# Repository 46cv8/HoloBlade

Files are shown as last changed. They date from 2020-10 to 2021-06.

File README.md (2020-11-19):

###################################################################<br/>
HoloBlade: An Open-Hardware Spatial Light Modulator Driver Platform<br/>
###################################################################<br/>

Overview:<br/>
Spatial light modulators (SLMs) are an important tool for applied optics research across a range of diverse fields such as holographic  displays, telecommunications, astronomy, microscopy and optical computing. However, contemporary SLMs are very much a high-end scientific tool and are not very accessible to the wider research community. HoloBlade is an attempt to democratise access to SLMs.<br/>

The primary application for HoloBlade is holographic display applications, but it is also applicable to adjacent research fields utilising SLMs. By providing an open-source SLM driver-stack, it is hoped to makes SLMs lower-cost, more accessbile and to use HoloBlade as a foundation platform to catalyse the development of Holographic Display Systems.

Directory Structure:
- fpga_firmware<br/>
  - verilog:   Main executable code for the FPGA is in here. Several components are generated from myHDL and have to be copied into here.<br/>
  - myHDL:     Most of the individual compoennts are designed, tested and simulated using myHDL and then sythesised to verilog. The myHDL components are in this directory along with scripts for generating them.<br/>
- electronics: Contains the HoloBlade bespoke electronics design files<br/>
- pc_software: Contains the GUI and driver calls to drive the HoloBlade driver-stack. Currently just supports .NET on Windows.<br/>
- mechanical:  STL files for the optomechanical mount for the main electornics board and SLM<br/>
- docs:        Any key supporting documentation (eg: datasheet)<br/>

License:<br/>
HoloBlade is released under the CERN Open Hardware Licence’s permissive variant, CERN-OHL-P v2, see https://cern.ch/cern-ohl.

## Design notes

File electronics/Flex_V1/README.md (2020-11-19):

All PCB files and intermediate files used in ordering the FFC Cable

Ordered from Elecrow.com Premium PCB service: https://www.elecrow.com/premium-pcb-service-p-1061.html

If they haven't changed their procedure, you will need to send the Gerber files (in flex_v1.zip),
PCB requirements (flex_pcb_requirements.xlsx) and the image showing location of stiffeners
(stiffner.png) to service@elecrow.com for a quote.

Leave most of the parameter in the requirements file as is, length, quantity and shipping address should be changed. May be worth testing with 0.5oz
copper as that may be much cheaper but have not tested this.

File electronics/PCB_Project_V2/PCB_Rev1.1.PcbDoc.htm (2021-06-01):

Reporting Options

# File in Previous Format

Date | : | 25/02/2021
Time | : | 10:41:34
Filename | : | D:\Dev\HoloBlade\electronics\PCB_Project_V2\PCB_Rev1.1.PcbDoc

Version | Warning

This file was generated by an earlier version of the software

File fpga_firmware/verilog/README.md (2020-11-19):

Firmware for FPGA to drive the Awesome Board

This firmware can either be run using the Lattice iCEcube2 tools or from the cli by invoking to the toolchain from the cli. A couple of things to note:
  - the iCEcube2 tools are good for configuration, but hard to get any serious amount of work done in (not really an editor/IDE)
  - the above is the main reason why i scripted to call from the cli, I use VSCode and the gitbash/mingw terminal within VSCode to develop the firmware
  - Holoblade_syn.prj and Holoblade_sbt.project will get overwritten by the iCEcube2 tools, so better to modify in there than editing files manually
  - these are the tools to build it, you use a separate tool to program called the Lattice Diamond Programmer
  - when running these tools, need to edit scripts/build.sh to point to root location of this project
  - i also put in the following symbolic link to deal with lattice installation issues: 'ln -s /c/lscc/iCEcube2.2017.08 /c/lscc/iCEcube2.2017.08'

From the CLI, I can compile the entire toolchain with the script with 'source scripts/build.sh'. To do this, need to make sure that the build script knows where the LSE toolchain is installed:
ie, set the following correctly in scripts/build.sh:
# LSE Versions
# Dev PC
# export ICE_ROOT=/d/ProgramFiles/Lattice
# Lab PC
export ICE_ROOT=/c/lscc/iCEcube2.2017.08

Also need to make sure that the programmer is set to the correct binary location and the correct COM port for programming is set. The programmer settings need to be configured in the Diamond Programmer App as a one-off, and then they can be saved and
the programmer can subsequently be run from the scripts here.

The directories are the following:
    - src: verilog code
    - phys: contraints (pin mappings, timing limitations, etc...)
    - scripts: scripts to help call tools from the cli
    - HoloBlade_Implmnt: All of the generated files (there's a lot of them) from the FPGA tools go here. Note that the name of this dir is a limitation of the Lattice tools

Andrew Kadis 6th August 2019

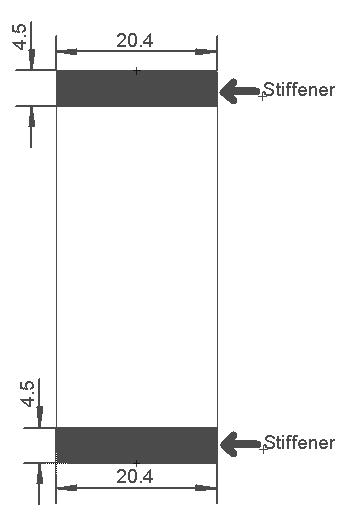
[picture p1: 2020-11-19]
electronics/Flex_V1/stiffener.png

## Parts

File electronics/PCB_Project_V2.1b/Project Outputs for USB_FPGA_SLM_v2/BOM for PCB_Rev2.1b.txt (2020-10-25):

Comment,Description,Designator,Footprint,LibRef,Quantity,Case Code,Mouser No.

"C0603C475K9PAC7411","Multilayer Ceramic Capacitors MLCC - SMD/SMT 6.3V 4.7uF 0603 X5R 10%","C1, C4, C9, C11","Cap_4.7uF","Cap_4.7uF","4","","80-C0603C475K9P7411"
"C1608X5R0J106K080AE","Multilayer Ceramic Capacitors MLCC - SMD/SMT 0603 6.3V 10uF X5R 10% Soft Term","C2, C6, C8, C13","Cap_10uF","Cap_10uF","4","","810-C1608X5R0J106KE"
"AC0603KRX7R9BB104","Multilayer Ceramic Capacitors MLCC - SMD/SMT 0.1uF 10% 50V AEC-Q200","C3, C5, C10, C12, C14, C15, C21, C22, C25, C26, C27, C28, C29, C30, C31, C32, C33, C34, C35, C36, C37, C38, C39, C40, C41, C42, C59, C74","Cap_0.1uF","Cap_0.1uF","28","","603-AC0603KR9BB104"
"C0402S471K3RACAUTO","Multilayer Ceramic Capacitors MLCC - SMD/SMT 25V 470pF X7R 0402 10% AEC-Q200","C7","CAP_470pF","Cap_470pF","1","0603","80-C0402S471K3RAUTO"
"CC0402KPX5R6BB104","Multilayer Ceramic Capacitors MLCC - SMD/SMT 100nF 10V X5R 10%","C16, C19, C23, C24, C44, C45, C46, C48, C49, C50, C51, C52, C53, C54, C55, C56, C62, C63, C64, C65, C66, C67, C68, C70, C72, C75, C76","CAP_0.1UF_0402","CAP_0.1uF_0402","27","0402","603-CC402KPX5R6BB104"
"C1005X5R0J475K050BC","Multilayer Ceramic Capacitors MLCC - SMD/SMT 0402 6.3V 4.7uF X5R 10% T: 0.5mm","C17, C43, C58, C60, C61, C71","CAP_4.7uF_0402","Cap_4.7uF_0402","6","0402","810-C1005X5R0J475K"
"C0603C180K5RACAUTO","Multilayer Ceramic Capacitors MLCC - SMD/SMT 50V 18pF 0603 X7R 10% AEC-Q200","C18, C20","CAP_18pF_0603","Cap_18pF_0603","2","0603","80-C0603C180K5RAUTO"
"C0402C682K5RECAUTO","Multilayer Ceramic Capacitors MLCC - SMD/SMT 50V 6800pF X7R 0402 10% AEC-Q200","C47, C57, C69","CAP_6700pF_0402","Cap_6800pF_0402","3","0402","80-C0402C682K5RECAUT"
"PGB1010402KR","ESD Suppressors / TVS Diodes PULSEGUARD 0402 ESD SUPPRESSOR","D1, D2","ESD_Suppressor","ESD_Suppresor","2","0402","576-PGB1010402KR"
"CDBU0520","Schottky Diodes & Rectifiers VR=20V, IO=500mA","D3","SchottkyDiode_CDBU0520","SDiode_CDBU0520","1","0603","750-CDBU0520"
"Header 3","Header, 3-Pin","DB7, DB8, GP0, GP1, RST, SIWU, WR","HDR1X3","Header 3","7","",""
"629105136821","Micro USB 2.0 Type B Receptacle WR-COM, Horizontal, SMT, with Pads and Pegs","J1","629105136821","629105136821","1","",""
"692622030100","Micro USB 3.0 Type B Receptacle WR-COM, Horizontal, SMT, with Pads","J2","692622030100","692622030100","1","",""
"FH39A-67S-0.3SHW(10)","FFC & FPC Connectors FPC ZIF CONN 67 POS SMT HORZ MNT","J3","Hirose_connector","FH39A-67S-0.3SHW(10)","1","","798-FH39A-67S-0.3SHW(10)"
"742863160","Ferrite Bead, 0603 [1608 Metric], 600 ohm, 500 mA, WE-CBF HF Series, 0.35 ohm, ± 25%","L1, L2","FerriteBeads","Ferrite Bead","2","0603","710-742863160"
"BLM18PG300SZ1D","Ferrite Beads 0603 30ohms 1000mA Auto Infotainment","L3","FerriteBeads","FerriteBeadForFT601","1","0603","81-BLM18PG300SZ1D"
"TLMS1000-GS08","Standard LEDs - SMD RED","LED1, LED2, LED3, LED4, LED5, LED6, LED7","LED_RED","LED_RED","7","0603","78-TLMS1000"
"Header 2","Header, 2-Pin","P1, P3, P5","HDR1X2","Header 2","3","",""
"Header 4","Header, 4-Pin","P2, P7","HDR2X2","Header 4","2","",""
"Header 3X2","Header, 3-Pin, Dual row","P6-GND","HDR2X3","Header 3X2","1","",""
"RT0603FRE13680RL","Thin Film Resistors - SMD 680 ohm 1% 50 ppm Thin Film","R1, R3, R21, R22, R23, R26, R36, R48","RES_680","Res_680","8","0603","603-RT0603FRE13680RL"
"CRCW06032K20JNEAC","Thick Film Resistors - SMD 1/10Watt 2.2Kohms 5% Commercial Use","R2, R6, R11","RES_2.2K","Res_2.2K","3","0603","71-CRCW06032K20JNEAC"
"ERJ2RKD33R0X","Thick Film Resistors - SMD 0402 Resistor 0.5% 100ppm 33Ohm","R4","Res_33_0402","Res_33_0402","1","0402","667-ERJ-2RKD33R0X"
"RT0603WRE0710KL","Thin Film Resistors - SMD 10K ohm 0.05% 50 ppm High-Precision","R5, R7, R8, R9, R14, R15, R17, R18, R25, R27, R39","RES_10K","Res_10K","11","0603","603-RT0603WRE0710KL"
"ERJ-3RBD1601V","Thick Film Resistors - SMD 0603 Resistor 0.5% 50ppm 1.6KOhm","R10","RES_1.6K","Res_1.6K","1","0603","667-ERJ-3RBD1601V"
"AC0603FR-1012KL","Thick Film Resistors - SMD 12K ohm 1% 1/10W AEC-Q200","R12","RES_12K","Res_12K","1","0603","603-AC0603FR-1012KL"
"CRCW06030000Z0EAC","Thick Film Resistors - SMD 1/10Watt 0ohms Commercial Use","R13, R16, R24, R30, R31, R32, R33, R34, R35, R37, R38, R40, R41, R42, R43, R44, R45, R46, R47","RES_0","Res_0","19","0603","71-CRCW06030000Z0EAC"
"AC0603JR-134K7L","Thick Film Resistors - SMD 4.7K ohm 5% 1/10W AEC-Q200","R19","RES_4.7K","Res_4.7K","1","0603","603-AC0603JR-134K7L"
"SR0603KR-07100KL","Thick Film Resistors - SMD 100K ohm 10% 75V AEC-Q200","R20","RES_100K","Res_100K","1","0603","603-SR0603KR-07100KL"
"SR0603KR-07100KL","Thick Film Resistors - SMD 100K ohm 10% 75V AEC-Q200","R49, R52","RESC1607X60N","Res_100K","2","0603","603-SR0603KR-07100KL"
"EXB-2HVR000V","Resistor Networks & Arrays 0402 Zero ohm Jumper Convex Term AEC-Q200","RN1, RN2","RESARRAY_0","ResArray_0","2","0402","667-EXB-2HVR000V"
"EXB-2HV330JV","Resistor Networks & Arrays 33 OHM 5%","RN3, RN4, RN5, RN6, RN7, RN8, RN9, RN10, RN11","RESARRAY_0","ResArray","9","","667-EXB-2HV330JV"
"SKU : COM-00097SMT- SWCH-08247","","S1","TACTILE-PTH","TAC_SWITCHPTH","1","",""
"testpoint","Testpoint for testing voltage","TP1, TP2, TP3, TP4, TP5, TP6, TP8, TP9","testpoint","Testpoint","8","",""
"MCP1700T-1202E/TT","LDO Voltage Regulators 250mA Adj LDO 2%","U1","MIC_LDO_1V2","MIC_LDO_1V2","1","","579-MCP1700T1202E/TT"
"MIC5205YM5-TR","LDO Voltage Regulators 150mA 1% Low Noise LDO","U2","MIC5205YM5","MIC5205YM5","1","","998-MIC5205YM5TR"
"MCP1700T-3302E/TT","3.3v LDO Voltage Regulators 250mA Adj LDO 2%","U3","MIC_LDO_3V3","MIC_LDO_3V3","1","","579-MCP1700T3302E/TT"
"LM1117MP-2.5/NOPB","LDO Voltage Regulators 800mA LDO Linear Reg","U4","LM1117MP-2.5/NOPB","LDO_2V5","1","","926-LM1117MP-2.5/NOPB"
"ICE40HX4K-TQ144","iCE40 HX4K Series FPGA Family, 3520 Logic Cells, 1.2 V Core, 80 K Embedded RAM Bits, 144-pin TQFP, Pb-Free, Tray","U5","LATC-TQFP-144_L","ICE40HX4K-TQ144","1","",""
"FT2232HL-Reel","Dual High Speed USB To Multipurpose UART/FIFO IC, 64-pin LQFP, Tape and Reel","U6","LQFP-64_N","FT2232HL-Reel","1","",""
"93LC56BT-E/MS","EEPROM 128x16 for FT2232","U7","EEPROM","EEPROM","1","","579-93LC56BT-E/MS"
"FT601Q-B-T","USB Interface IC USB 3.0 Super-Speed 32Bits Sync FIFO","U8","FT601_NoGND_Pad","FT601Q-B-T","1","",""
"MT25QL128ABA1ESE-0SIT TR","NOR Flash SPI FLASH NOR SLC 32MX4 SOIC","U9","Flash","Flash","1","","340-224871-REEL"
"TXS0108EPWR","Integrated Circuit","U10","SOP65P640X120-20N","Level_Shfter_8bits","1","",""
"DSC6101JI2A-024.0000","Standard Clock Oscillators MEMS Oscillator, Ultra Low Power, LVCMOS, -40C-85C, 25ppm, 2.5x2.0mm","X1","24MHzOscillator","24MHzOscillator","1","","579-C6101JI2A0240000"
"ABM8G-30.000MHZ-18-D2Y-T","Crystals 30.000MHz 18pF 30ppm -40C +85C","X2","30MHzOscillatorV2","30MHzOscillator","1","",""
"ECS-3225S33-120-FN-TR","Standard Clock Oscillators 12MHz 3.3V 10ppm -40C +85C","X3","12MHzOscillator","12MHzOscillator","1","","520-3225S33-120-FNT"

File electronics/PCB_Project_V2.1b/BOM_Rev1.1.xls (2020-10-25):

Item | Comment | Description | Designator | Footprint | LibRef | Package | Quantity | Unit Price | Price for each component | NOTE
1 | C0603C475K9PAC7411 | Multilayer Ceramic Capacitors MLCC - SMD/SMT 6.3V 4.7uF 0603 X5R 10% | C1, C4, C9, C11 | Cap_4.7uF | Cap_4.7uF | 0603 | 4 |  | US$0.0000
2 | C1608X5R0J106K080AE | Multilayer Ceramic Capacitors MLCC - SMD/SMT 0603 6.3V 10uF X5R 10% Soft Term | C2, C6, C8, C13 | Cap_10uF | Cap_10uF | 0603 | 4 |  | US$0.0000 | 5-7work days
3 | AC0603KRX7R9BB104 | Multilayer Ceramic Capacitors MLCC - SMD/SMT 0.1uF 10% 50V AEC-Q200 | C3, C5, C10, C12, C14, C15, C21, C22, C25, C26, C27, C28, C29, C30, C31, C32, C33, C34, C35, C36, C37, C38, C39, C40, C41, C42, C59, C74 | Cap_0.1uF | Cap_0.1uF | 0603 | 28 |  | US$0.0000
4 | C0402S471K3RACAUTO | Multilayer Ceramic Capacitors MLCC - SMD/SMT 25V 470pF X7R 0402 10% AEC-Q200 | C7 | CAP_470pF | Cap_470pF | 0402 | 1 |  | US$0.0000 | 5-7work days
5 | CC0402KPX5R6BB104 | Multilayer Ceramic Capacitors MLCC - SMD/SMT 100nF 10V X5R 10% | C16, C19, C23, C24, C44, C45, C46, C48, C49, C50, C51, C52, C53, C54, C55, C56, C62, C63, C64, C65, C66, C67, C68, C70, C72, C75, C76 | CAP_0.1UF_0402 | CAP_0.1uF_0402 | 0402 | 27 |  | US$0.0000
6 | C1005X5R0J475K050BC | Multilayer Ceramic Capacitors MLCC - SMD/SMT 0402 6.3V 4.7uF X5R 10% T: 0.5mm | C17, C43, C58, C60, C61, C71 | CAP_4.7uF_0402 | Cap_4.7uF_0402 | 0402 | 6 |  | US$0.0000 | 5-7work days
7 | C0603C180K5RACAUTO | Multilayer Ceramic Capacitors MLCC - SMD/SMT 50V 18pF 0603 X7R 10% AEC-Q200 | C18, C20 | CAP_18pF_0603 | Cap_18pF_0603 | 0603 | 2 |  | US$0.0000
8 | C0402C682K5RECAUTO | Multilayer Ceramic Capacitors MLCC - SMD/SMT 50V 6800pF X7R 0402 10% AEC-Q200 | C47, C57, C69 | CAP_6700pF_0402 | Cap_6800pF_0402 | 0402 | 3 |  | US$0.0000 | 5-7work days
9 | PGB1010402KR | ESD Suppressors / TVS Diodes PULSEGUARD 0402 ESD SUPPRESSOR | D1, D2 | ESD_Suppressor | ESD_Suppresor | 0402 | 2 |  | US$0.0000
10 | CDBU0520 | Schottky Diodes & Rectifiers VR=20V, IO=500mA | D3 | SchottkyDiode_CDBU0520 | SDiode_CDBU0520 | 0603 | 1 |  | US$0.0000 | 5-7work days
11 | 629105136821 | Micro USB 2.0 Type B Receptacle WR-COM, Horizontal, SMT, with Pads and Pegs | J1 | 629105136821 | 629105136821 | USB3 | 1 |  | US$0.0000 | 5-7work days
12 | 692622030100 | Micro USB 3.0 Type B Receptacle WR-COM, Horizontal, SMT, with Pads | J2 | 692622030100 | 692622030100 | USB2 | 1 |  | US$0.0000 | 5-7work days
13 | FH39A-67S-0.3SHW(10) | FFC & FPC Connectors FPC ZIF CONN 67 POS SMT HORZ MNT | J3 | Hirose_connector | FH39A-67S-0.3SHW(10) |  | 1 |  | US$0.0000 | 5-7work days
14 | 742863160 | Ferrite Bead, 0603 [1608 Metric], 600 ohm, 500 mA, WE-CBF HF Series, 0.35 ohm, ± 25% | L1, L2 | FerriteBeads | Ferrite Bead | 0603 | 2 |  | US$0.0000 | 5-7work days
15 | BLM18PG300SZ1D | Ferrite Beads 0603 30ohms 1000mA Auto Infotainment | L3 | FerriteBeads | FerriteBeadForFT601 | 0603 | 1 |  | US$0.0000 | 5-7work days
16 | TLMS1000-GS08 | Standard LEDs - SMD RED | LED1, LED2, LED3, LED4, LED5, LED6, LED7 | LED_RED | LED_RED | 0603 | 7 |  | US$0.0000
17 | RT0603FRE13680RL | Thin Film Resistors - SMD 680 ohm 1% 50 ppm Thin Film | R1, R3, R21, R22, R23, R26, R36, R48 | RES_680 | Res_680 | 0603 | 8 |  | US$0.0000
18 | CRCW06032K20JNEAC | Thick Film Resistors - SMD 1/10Watt 2.2Kohms 5% Commercial Use | R2, R6, R11 | RES_2.2K | Res_2.2K | 0603 | 3 |  | US$0.0000
19 | ERJ2RKD33R0X | Thick Film Resistors - SMD 0402 Resistor 0.5% 100ppm 33Ohm | R4, R28, R29 | Res_33_0402 | Res_33_0402 | 0402 | 3 |  | US$0.0000 | 5-7work days
20 | RT0603WRE0710KL | Thin Film Resistors - SMD 10K ohm 0.05% 50 ppm High-Precision | R5, R7, R8, R9, R14, R15, R17, R18, R25, R27, R39 | RES_10K | Res_10K | 0603 | 11 |  | US$0.0000 | 5-7work days
21 | ERJ-3RBD1601V | Thick Film Resistors - SMD 0603 Resistor 0.5% 50ppm 1.6KOhm | R10 | RES_1.6K | Res_1.6K | 0603 | 1 |  | US$0.0000 | 5-7work days
22 | AC0603FR-1012KL | Thick Film Resistors - SMD 12K ohm 1% 1/10W AEC-Q200 | R12 | RES_12K | Res_12K | 0603 | 1 |  | US$0.0000
23 | CRCW06030000Z0EAC | Thick Film Resistors - SMD 1/10Watt 0ohms Commercial Use | R13, R16, R24, R30, R31, R32, R33, R34, R35, R37, R38, R40, R41, R42, R43, R44, R45, R46, R47 | RES_0 | Res_0 | 0603 | 19 |  | US$0.0000
24 | AC0603JR-134K7L | Thick Film Resistors - SMD 4.7K ohm 5% 1/10W AEC-Q200 | R19 | RES_4.7K | Res_4.7K | 0603 | 1 |  | US$0.0000
25 | SR0603KR-07100KL | Thick Film Resistors - SMD 100K ohm 10% 75V AEC-Q200 | R20 | RES_100K | Res_100K | 0603 | 1 |  | US$0.0000
26 | EXB-2HVR000V | Resistor Networks & Arrays 0402 Zero ohm Jumper Convex Term AEC-Q200 | RN1, RN2 | RESARRAY_0 | ResArray_0 | 0402 Array | 2 |  | US$0.0000 | 5-7work days
27 | EXB-2HV330JV | Resistor Networks & Arrays 33 OHM 5% | RN3, RN4, RN5, RN7, RN8, RN6, RN9, RN10, RN11 | RESARRAY_0 | ResArray | 0402 Array | 9 |  | US$0.0000 | 5-7work days
28 | MCP1700T-1202E/TT | LDO Voltage Regulators 250mA Adj LDO 2% | U1 | MIC_LDO_1V2 | MIC_LDO_1V2 | SOT-23-3 | 1 |  | US$0.0000
29 | MIC5205YM5-TR | LDO Voltage Regulators 150mA 1% Low Noise LDO | U2 | MIC5205YM5 | MIC5205YM5 | SOT-23-5 | 1 |  | US$0.0000
30 | MCP1700T-3302E/TT | 3.3v LDO Voltage Regulators 250mA Adj LDO 2% | U3 | MIC_LDO_3V3 | MIC_LDO_3V3 | SOT-23-3 | 1 |  | US$0.0000
31 | LM1117MP-2.5/NOPB | LDO Voltage Regulators 800mA LDO Linear Reg | U4 | LM1117MP-2.5/NOPB | LDO_2V5 | SOT-223-4 | 1 |  | US$0.0000
32 | ICE40HX4K-TQ144 | iCE40 HX4K Series FPGA Family, 3520 Logic Cells, 1.2 V Core, 80 K Embedded RAM Bits, 144-pin TQFP, Pb-Free, Tray | U5 | LATC-TQFP-144_L | ICE40HX4K-TQ144 | TQFP-144 | 1 |  | US$0.0000 | 5-7work days
33 | FT2232HL-Reel | Dual High Speed USB To Multipurpose UART/FIFO IC, 64-pin LQFP, Tape and Reel | U6 | LQFP-64_N | FT2232HL-Reel | LQFP-64 | 1 |  | US$0.0000
34 | 93LC56BT-E/MS | EEPROM 128x16 for FT2232 | U7 | EEPROM | EEPROM | MSOP-8 | 1 |  | US$0.0000 | 5-7work days
35 | FT601Q-B-T | USB Interface IC USB 3.0 Super-Speed 32Bits Sync FIFO | U8 | FT601_NoGND_Pad | FT601Q-B-T | 76-QFN | 1 |  | US$0.0000 | 5-7work days
36 | MT25QL128ABA1ESE-0SIT TR | NOR Flash SPI FLASH NOR SLC 32MX4 SOIC | U9 | Flash | Flash | SOP2-8 | 1 |  | US$0.0000
37 | TXS0108EPWR | Integrated Circuit | U10 | SOP65P640X120-20N | Level_Shfter_8bits | TSSOP-20 | 1 |  | US$0.0000
38 | DSC6101JI2A-024.0000 | Standard Clock Oscillators MEMS Oscillator, Ultra Low Power, LVCMOS, -40C-85C, 25ppm, 2.5x2.0mm | X1 | 24MHzOscillator | 24MHzOscillator | VLGA-4 | 1 |  | US$0.0000 | 5-7work days
39 | ABM8G-30.000MHZ-18-D2Y-T | Crystals 30.000MHz 18pF 30ppm -40C +85C | X2 | 30MHzOscillatorV2 | 30MHzOscillator | SMD/SMT | 1 |  | US$0.0000 | 5-7work days
40 | ECS-3225S33-120-FN-TR | Standard Clock Oscillators 12MHz 3.3V 10ppm -40C +85C | X3 | 12MHzOscillator | 12MHzOscillator | 6-SMD, No Lead | 1 |  | US$0.0000 | 5-7work days
 |  |  |  |  |  | Total | 163 |  | $0.000
 |  |  |  |  |  |  |  | Total amount for 5sets | US$0
 |  |  |  |  |  |  |  | Total weight
 |  |  |  |  |  |  |  | Quote based on Comment

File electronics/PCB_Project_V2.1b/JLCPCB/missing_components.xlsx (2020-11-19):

Designator | Comment | Footprint | Quantity
L3 | BLM18PG300SZ1D | FERRITEBEADS | 1
J3 | FH39A-67S-0.3SHW(10) | HIROSE_CONNECTOR | 1
D3 | CDBU0520 | SCHOTTKYDIODE_CDBU0520 | 1
L1,L2 | 742863160 | FERRITEBEADS | 2
C7 | C0402S471K3RACAUTO | CAP_470PF | 1
U3 | MCP1700T-3302E/TT | MIC_LDO_3V3 | 1
C2,C6,C8,C13 | C1608X5R0J106K080AE | CAP_10UF | 4
C1,C4,C9,C11 | C0603C475K9PAC7411 | CAP_4.7UF | 4
D1,D2 | PGB1010402KR | ESD_SUPPRESSOR | 2
U1 | MCP1700T-1202E/TT | MIC_LDO_1V2 | 1
U2 | MIC5205YM5-TR | MIC5205YM5 | 1
U6 | FT2232HL-REEL | LQFP-64_N | 1
U10 | TXS0108EPWR | SOP65P640X120-20N | 1
R4 | ERJ2RKD33R0X | RES_33_0402 | 1
LED1,LED2,LED3,LED4,LED5,LED6,LED7 | TLMS1000-GS08 | LED_RED | 7
R13,R16,R24,R30,R31,R32,R33,R34,R35,R37,R38,R40,R41,R42,R43,R44,R45,R46,R47 | CRCW06030000Z0EAC | RES_0 | 19
R19 | AC0603JR-134K7L | RES_4.7K | 1
R2,R6,R11 | CRCW06032K20JNEAC | RES_2.2K | 3
J2 | 692622030100 | 692622030100 | 1
R10 | ERJ-3RBD1601V | RES_1.6K | 1
X1 | DSC6101JI2A-024.0000 | 24MHZOSCILLATOR | 1
P6-GND | HEADER 3X2 | HDR2X3 | 1
X2 | ABM8G-30.000MHZ-18-D2Y-T | 30MHZOSCILLATORV2 | 1
P1,P3,P5 | HEADER 2 | HDR1X2 | 3
RN3,RN4,RN5,RN6,RN7,RN8,RN9,RN10,RN11 | EXB-2HV330JV | RESARRAY_0 | 9
U8 | FT601Q-B-T | FT601_NOGND_PAD | 1
U7 | 93LC56BT-E/MS | EEPROM | 1
R20 | SR0603KR-07100KL | RES_100K | 1
U4 | LM1117MP-2.5/NOPB | LM1117MP-2.5/NOPB | 1
U9 | MT25QL128ABA1ESE-0SIT TR | FLASH | 1
TP1,TP2,TP3,TP4,TP5,TP6,TP8,TP9 | TESTPOINT | TESTPOINT | 8
U5 | ICE40HX4K-TQ144 | LATC-TQFP-144_L | 1
R12 | AC0603FR-1012KL | RES_12K | 1
DB7,DB8,GP0,GP1,RST,SIWU,WR | HEADER 3 | HDR1X3 | 7
C18,C20 | C0603C180K5RACAUTO | CAP_18PF_0603 | 2
RN1,RN2 | EXB-2HVR000V | RESARRAY_0 | 2
J1 | 629105136821 | 629105136821 | 1
P2,P7 | HEADER 4 | HDR2X2 | 2
S1 | SKU : COM-00097SMT- SWCH-08247 | TACTILE-PTH | 1
X3 | ECS-3225S33-120-FN-TR | 12MHZOSCILLATOR | 1

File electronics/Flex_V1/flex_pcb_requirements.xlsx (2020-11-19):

Premium PCB Service Technology Requirement
PCB Name & Version | flex v0.1
PCB Material PCB板材： | (Rigid)FR－4 Flex | PCB Qty PCB 数量 | （ 30 ）
PCB Size PCB大小： | cm mm inch | ( 20.4 ) × ( 50 )
PCB Layer PCB层数： | 2 | 4 | other:( 1 )
Thickness PCB厚度： | 0.8mm | 1.2mm | other:( 0.2mm )
 | 1mm | 1.6mm
Copper Weight 铜厚： | 1oz | 2oz | other:( )
PCB Colour 阻焊颜色： | Green 绿色 | White 白色 | Black 黑色
 | Red 红色 | Blue 蓝色 | other:( )
Silkscreen 字符颜色： | White 白色 | Black 黑色 | other:( None )
Pads Finished 焊盘喷镀： | (Hasl-lead free) 无铅喷锡 | (Hasl) 含铅喷锡 | (ENIG) 沉镍金
Via solder mask 阻焊覆盖： | solder mask cover 过孔盖油 | solder mask opening 过孔开窗 | No vias
Minimum trace/space (mm) 最小线宽 | 0.1mm | Minimum hole size (mm) 最小孔径 | No holes
Special requirements 特殊工艺： | Yes | (Put requirements here)
价格/Price | Premium PCB service | PCB with normal price | The PCB with normal price is listed online, If there isn't a choice meets your requirement, get quotation off-line.
Comment: | Stiffner specified in attached image
Shipping Address | 43 Princess Court Cambridge - CB2 1JJ - UK

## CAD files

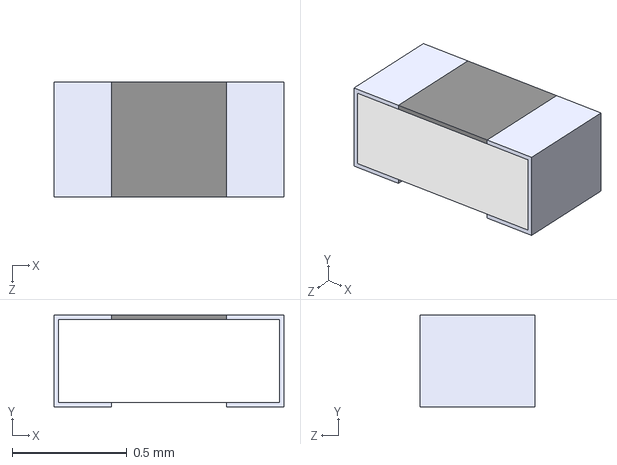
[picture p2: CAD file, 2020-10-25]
electronics/PCB_Project_V2.1b/ERJ2RKD33R0X.STEP
1 x 0.4 x 0.5 mm

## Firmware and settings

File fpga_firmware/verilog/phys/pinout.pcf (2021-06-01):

# ##############################################################################

# iCEcube PCF

# Version:            2017.08.27940

# Family & Device:    iCE40HX4K

# Package:            TQ144

# ##############################################################################

###IOSet List 4

# FPGA
set_io ICE_SYSCLK 93

# Debug
set_io DEBUG_5 81
set_io DEBUG_6 82
set_io DEBUG_0 83
set_io DEBUG_1 84
set_io DEBUG_2 85
set_io DEBUG_3 87
# NetTP8
set_io DEBUG_8 63
# NetTP9
set_io DEBUG_9 64

# FT2232H UART
set_io DCD 73
set_io DSR 74
set_io DTR 75
set_io CTS 76
set_io RST 78
set_io UART_TX 79
set_io UART_RX 80

# SPI
set_io SEN 141
set_io SCK 144
set_io SOUT 139
set_io SDAT 143

# Bluejay Control
# Control Signals
set_io UPDATE 88
set_io RESET 142
set_io SLM_CLK 95
set_io INVERT 91
set_io SYNC 90
set_io VALID 94

# Data
set_io DATA31 137 
set_io DATA0  138 
set_io DATA30 136 
set_io DATA29 135
set_io DATA1  134
set_io DATA28 130
set_io DATA27 129
set_io DATA2  128
set_io DATA26 125
set_io DATA25 124
set_io DATA3  122
set_io DATA24 121
set_io DATA23 120
set_io DATA4  119
set_io DATA22 118
set_io DATA21 117
set_io DATA5  116
set_io DATA20 115
set_io DATA19 114
set_io DATA6  113
set_io DATA18 112
set_io DATA17 110
set_io DATA7  107
set_io DATA16 106
set_io DATA15 105
set_io DATA8  104
set_io DATA14 102
set_io DATA13 101
set_io DATA9  99
set_io DATA12 98
set_io DATA11 97
set_io DATA10 96

# FT601
# Bank 3 Pins
set_io DEBUG_N_8 1 # Created as DEBUG_N_8 was not defined prior but used to map to TP7 on board
set_io FT_OE 2
set_io FT_RD 3
set_io FT_WR 4 # Can be used as debug point when configured with jumper
set_io FT_SIWU 7 # Can be used as debug point when configured with jumper
set_io FR_RXF 8
set_io FT_TXE 9
# set_io FIFO_BE3 10 # Changing to FT_RESET was FIFO_BE3 AND can be used as debug point when configured with jumper
set_io FT_RESET 10 # Changing to FT_RESET was FIFO_BE3 AND can be used as debug point when configured with jumper
# set_io FIFO_BE2 11 # Changing to FT_GPIO0 was FIFO_BE2 AND can be used as debug point when configured with jumper
set_io FT_GPIO0 11 # Changing to FT_GPIO0 was FIFO_BE2 AND can be used as debug point when configured with jumper
#  set_io FIFO_BE1 12 # Changing to FT_GPIO1 was FIFO_BE1 AND can be used as debug point when configured with jumper
set_io FT_GPIO1 12 # Changing to FT_GPIO1 was FIFO_BE1 AND can be used as debug point when configured with jumper
# set_io FIFO_BE0 15 # Changed to DEBUG_N_7 was FIFO_BE0 AND can be used as debug point when configured with jumper
set_io DEBUG_N_7 15 # Changed to DEBUG_N_7 was FIFO_BE0 AND can be used as debug point when configured with jumper
set_io FIFO_D31 16
set_io FIFO_D30 17
set_io FIFO_D29 18
set_io FIFO_D28 19
set_io FIFO_D27 20
set_io FIFO_CLK 21
set_io FIFO_D26 22
set_io FIFO_D25 23
set_io FIFO_D24 24
set_io FIFO_D23 25
set_io FIFO_D22 26
set_io FIFO_D21 28
set_io FIFO_D20 29
set_io FIFO_D19 31
set_io FIFO_D18 32
set_io FIFO_D17 33
set_io FIFO_D16 34
# Bank 2 Pins
set_io FIFO_D15 37
set_io FIFO_D14 38
set_io FIFO_D13 39
set_io FIFO_D12 41
set_io FIFO_D11 42
set_io FIFO_D10 43
set_io FIFO_D9  44
set_io FIFO_D8  45
set_io FIFO_D7  47
set_io FIFO_D6  48
set_io FIFO_D5  49
set_io FIFO_D4  55
set_io FIFO_D3  56
set_io FIFO_D2  60
set_io FIFO_D1  61
set_io FIFO_D0  62

# Programming
#set_io ICE_CLK 52 # for linux build it doesn't seem to properly assign tri-state so we need to manually create another net so we can use the SB_IO or SB_GB_IO primitives commented out for now as its unused
#set_io ICE_CDONE 65 # for linux build can't bind to pin 65 removing https://github.com/YosysHQ/icestorm/issues/269
#set_io ICE_CREST 66 # for linux build can't bind to pin 66 removing https://github.com/YosysHQ/icestorm/issues/269
#set_io ICE_MISO 67
#set_io ICE_MOSI 68
#set_io ICE_SCK  70
#set_io ICE_SS_B 71

# Unused

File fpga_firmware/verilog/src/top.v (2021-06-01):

/* 
* Top module for HoloBlade Board
*/

module top(

    // FPGA
    input ICE_SYSCLK, 

    // FT2232H UART
    output DCD,
    output DSR,
    output DTR,
    output CTS,
    output RST,
    input  UART_RX,
    output UART_TX,

    // Bluejay SPI
    output SEN,
    output SCK,
    input  SOUT, // ie: MISO
    output SDAT, // ie: MOSI

    // Bluejay Control
    // Control Signals
    output UPDATE,
    output RESET,
    output SLM_CLK,
    output INVERT,
    output SYNC,
    output VALID,
    // Data
    output DATA31,
    output DATA0,
    output DATA30,
    output DATA29,
    output DATA1,
    output DATA28,
    output DATA27,
    output DATA2,
    output DATA26,
    output DATA25,
    output DATA3,
    output DATA24,
    output DATA23,
    output DATA4,
    output DATA22,
    output DATA21,
    output DATA5,
    output DATA20,
    output DATA19,
    output DATA6,
    output DATA18,
    output DATA17,
    output DATA7,
    output DATA16,
    output DATA15,
    output DATA8 ,
    output DATA14,
    output DATA13,
    output DATA12,
    output DATA11,
    output DATA9,
    output DATA10,

    // FT601
    // Bank 1 Pins
    output DEBUG_N_8, // was not defined before but corresponded to TP7 on new header on V2.1b board (now debug output)
    output FT_OE,
    output FT_RD,
    output FT_WR, // (can be used as a debug output when jumper is set on V2.1b board)
    output FT_SIWU, // (can be used as a debug output when jumper is set on V2.1b board)
    input  FR_RXF,
    input  FT_TXE,
    // input  FIFO_BE3, // same pin as output FT_RESET on V2.1b board
    output FT_RESET, // same as input FIFO_BE3 on V1.1 board (can be used as a debug output when jumper is set on V2.1b board)
    // input  FIFO_BE2, // same pin as output FT_GPIO0 on V2.1b board
    // input FT_GPIO0, // same as input FIFO_BE2 on V1.1 board
    output FT_GPIO0, // same as input FIFO_BE2 on V1.1 board (can be used as a debug output when jumper is set on V2.1b board)
    // input  FIFO_BE1, // same pin as output FT_GPIO1 on V2.1b board
    // input FT_GPIO1, // same as input FIFO_BE1 on V1.1 board
    output FT_GPIO1, // same as input FIFO_BE1 on V1.1 board (can be used as a debug output when jumper is set on V2.1b board)
    // input  FIFO_BE0, // same pin as output DEBUG_N_7 on V2.1b board
    output DEBUG_N_7, // same as input FIFO_BE0 on V1.1 board (now debug output)
    input  FIFO_D31,
    input  FIFO_D30,
    input  FIFO_D29,
    input  FIFO_D28,
    input  FIFO_D27,
    input  FIFO_CLK,
    input  FIFO_D26,
    input  FIFO_D25,
    input  FIFO_D24,
    input  FIFO_D23,
    input  FIFO_D22,
    input  FIFO_D21,
    input  FIFO_D20,
    input  FIFO_D19,
    input  FIFO_D18,
    input  FIFO_D17,
    input  FIFO_D16,
    // Bank 2 Pins
    input FIFO_D15,
    input FIFO_D14,
    input FIFO_D13,
    input FIFO_D12,
    input FIFO_D11,
    input FIFO_D10,
    input FIFO_D9,
    input FIFO_D8,
    input FIFO_D7,
    input FIFO_D6,
    input FIFO_D5,
    input FIFO_D4,
    input FIFO_D3,
    input FIFO_D2,
    input FIFO_D1,
    input FIFO_D0,

    // Debug
    output DEBUG_0,
    output DEBUG_1,
    output DEBUG_2,
    output DEBUG_3,
    output DEBUG_5,
    output DEBUG_6,
    output DEBUG_8,
    output DEBUG_9
    //

    // Programming Pins
    //output ICE_CLK, // for linux build it doesn't seem to properly assign tri-state to this output resulting in a pulldown of the usb clock so I've just disabled it for now
    //output ICE_CDONE, // for linux build can't bind to pin 65 removing https://github.com/YosysHQ/icestorm/issues/269
    //output ICE_CREST, // for linux build can't bind to pin 66 removing https://github.com/YosysHQ/icestorm/issues/269
    //output ICE_MISO,
    //output ICE_MOSI,
    //output ICE_SCK ,
    //output ICE_SS_B,

    // Unused Pins
    // output UNUSED_63,
    // output UNUSED_64

);




// assign DEBUG_0 = 1;
// assign DEBUG_1 = 0;//CLK;
// assign DEBUG_2 = 1;
// assign DEBUG_3 = sysclk_unbuf;





// Route the Uart Rx out of the chip
// assign DEBUG_3 = UART_RX;













////////////////////////
/////// Debug //////////
////////////////////////
// GPIOs for Debug
wire debug_ch1;
wire debug_ch2;
wire debug_ch3;
wire debug_ch4;
// Map to scope probes
// assign DEBUG_9 = debug_ch1; // Goes to TP9
// assign DEBUG_8 = debug_ch2; // Goes to TP8
// assign DEBUG_5 = debug_ch3; // Goes to p5
// assign DEBUG_6 = debug_ch4; // Goes to p6
// GPIOs attached to LEDs
wire debug_led2;
wire debug_led3;
wire debug_led4;
assign DEBUG_0 = debug_led4;


// Temp for LA
wire DEBUG_4;
wire DEBUG_7;
assign DEBUG_4 = DEBUG_9;
assign DEBUG_7 = DEBUG_8;

// assign DEBUG_1 = debug_led3;
// assign DEBUG_2 = debug_led2;
// Drive unused pins to High-Impedance Output
// assign DEBUG_5 = 1'bz;
// assign DEBUG_6 = 1'bz;

// Route out clock
// assign debug_ch1 = fpga_clk;

// LEDs - drive them with a counter
// Counter 
reg [31:0] led_counter = 32'b0;
always @ (posedge fpga_clk) begin
    led_counter <= led_counter + 1;
end
assign debug_led4 = led_counter[24];










////////////////////////
//////// FPGA //////////
////////////////////////

// Clock
wire fpga_clk;
clock clock_inst(

  // Main Clock
  .i_xtal(ICE_SYSCLK),
  .o_sys_clk(fpga_clk)
	
 );

// Reset lines - all driven off a single signal
wire reset_all_cmd_w;
reg reset_all_cmd_r = 1;                     // Start with High on as we want to reset at startup
assign reset_all_cmd_w = reset_all_cmd_r;
// TODO: Reset pulses low for 100ms
/*******************************************************************
************* Clock Divider from 50MHz to 1MHz *********************
*******************************************************************/
// Module to step 50MHz System Clock down to 1Hz Clock for SPI
// reg spi_clk;
wire reset_all_w;
reg reset_all_r = 0;
reg[3:0] reset_clk_counter = reset_countdown; // Start at reset_countdown as we want to reset at startup
// We need to hold reset dow for at least tReset (100ns)
// Hence if we pulse for 10 cycles at 50MHz, this is 200ns, plenty of headroom
parameter reset_countdown = 4'd10;
always @ (posedge fpga_clk) begin
  
  // Default state is no reset
  reset_all_r <= 0;

	if(reset_all_cmd_w==1) begin
		// Start reset countdown if command has been given
		reset_clk_counter <= reset_countdown;
    reset_all_r <= 1;
	end else begin
    // Counting down, pull reset high and decrement
    if(reset_clk_counter>0) begin
      // Decrement and hold reset high
  	  reset_clk_counter <= reset_clk_counter - 1'b1;
      reset_all_r <= 1;
    end
  end

end
// Route out the register pulse value from above to the reset wire
assign reset_all_w = reset_all_r;

// Debug
// assign debug_ch4 = debug_check;
// assign debug_ch4 = reset_all_w;

// Debug
// assign debug_ch1 = UART_RX;
// assign debug_ch2 = UART_TX;
// assign debug_ch4 = start_tx;
// assign debug_ch2 = spi_busy_falling_edge;
// assign debug_ch4 = spi_busy;
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

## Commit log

2020-10-25 version 2.1b pcb
    [BOM for PCB_Rev2.1b.csv, BOM for PCB_Rev2.1b.xls, BOM_Rev1.1.xls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]
2020-10-25 added notes for v2.1b pcb design optional debug outputs and removal of be0-be3 inputs
2020-11-17 fixed pcf error for new debug line for next pnr build
    [pinout_nextpnr.pcf]
2020-11-19 flex pcb details
    [flex_pcb_requirements.xlsx, flex_v1.brd, flex_v1.sch]
2020-11-19 jlcpcb missing and found components
    [missing_components.xlsx]
2020-11-19 fixed default pinout for lattice tools
    [pinout.pcf]
2020-11-19 fixes to get open source build working with yosys nextpnr need to remove ice_clk too because the tristate isn't getting set on linux properly and it's driving the usb2 clk signal down to half it's re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
    [pinout_nextpnr.pcf, top.v]
2020-11-21 fix bad verilog that fails for lattice
    [top.v]
2021-06-01 enabling debug signals on new PCB for testing
